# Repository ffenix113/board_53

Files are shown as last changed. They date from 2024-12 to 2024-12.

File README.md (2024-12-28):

# board_53

An Arduino Nano-sized board based on [nRF5340](https://www.nordicsemi.com/Products/nRF5340).
Idea is to have modern and accessible alternative to a sea of nRF52840 boards.

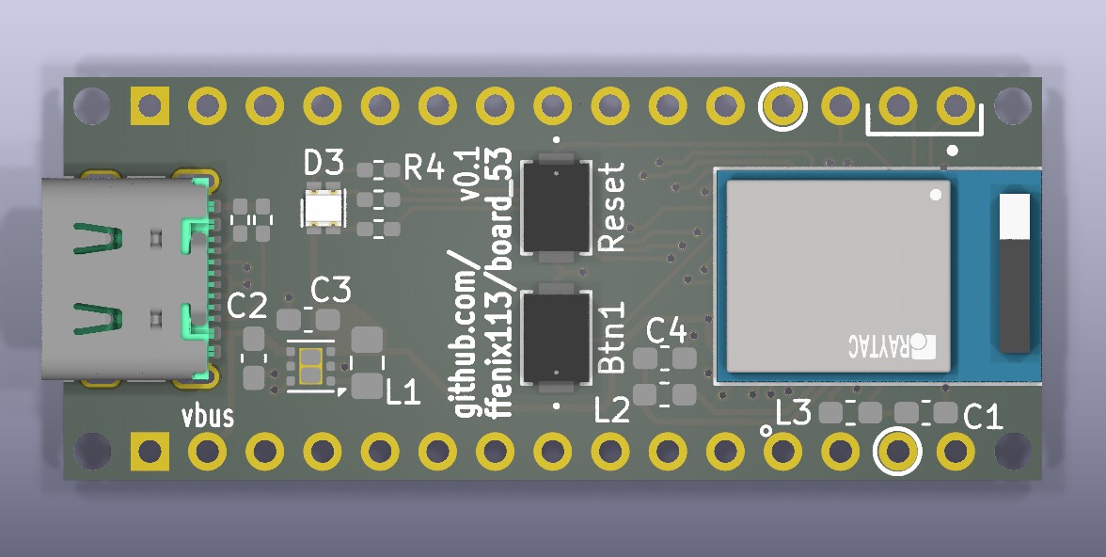
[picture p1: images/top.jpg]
top

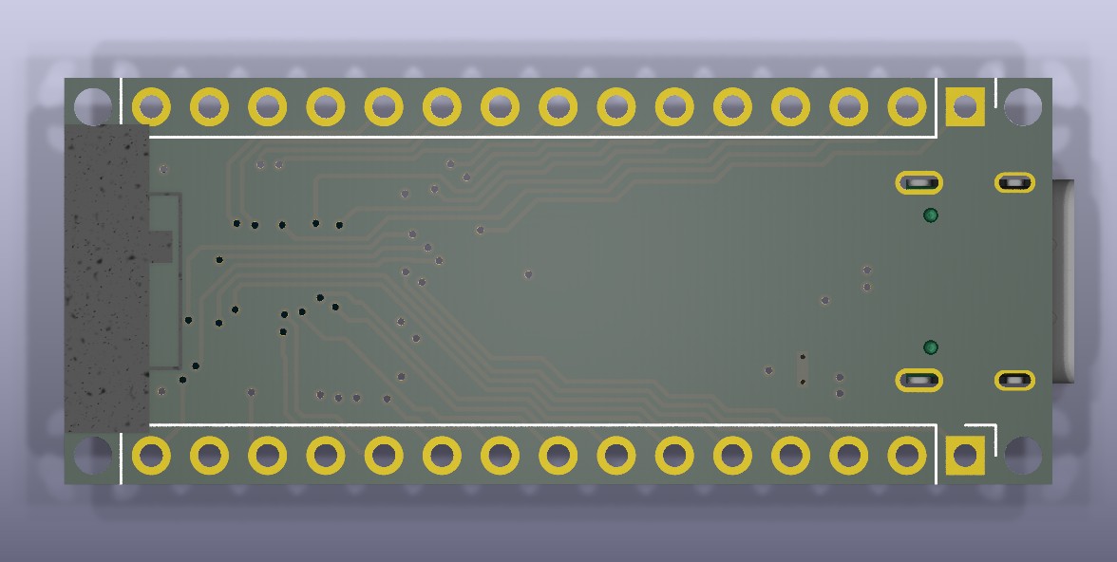
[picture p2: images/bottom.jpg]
bottom


## Features
* Similar, but not identical, pinout to [Arduino Nano 33 BLE](https://docs.arduino.cc/hardware/nano-33-ble/).
* Based on Raytac [MDBT53-1M](https://www.raytac.com/product/ins.php?index_id=121) (nRF5340).
* USB-C connector.
* RGB LED.
* Uses TI [TPS62291](https://www.ti.com/lit/ds/symlink/tps62293.pdf) for better efficiency. This also allows to use batteries in 2.3-6.0 V range (no on-board charger).
* Two buttons: Reset & User configurable.
* SWD pins on the edges.
* Chip antena for better wireless.
* Rather easy to solder this board at home.

## Notes
1. This board is not (yet?) available in Zephyr. Zephyr board definition from this repository should be used when building for this board.
2. Board will be revisioned to improve & simplify design.
3. Buck converter is used to improve efficiency, but maybe will be converted for LDO in next revisions.
4. Bootloader is not required, but MCUBoot can be used as one. UF2 bootloader is not currently (15 Dec, 2024) available for nRF53.
5. There are 0402 resistors in revision 0.1, which will be replaced by 0603(or even 0804) in next revision for easier placing & soldering.

## Contact
* For issues and proposals please use Issues.
* For direct contact please use: board_53@ffenix113.addy.io

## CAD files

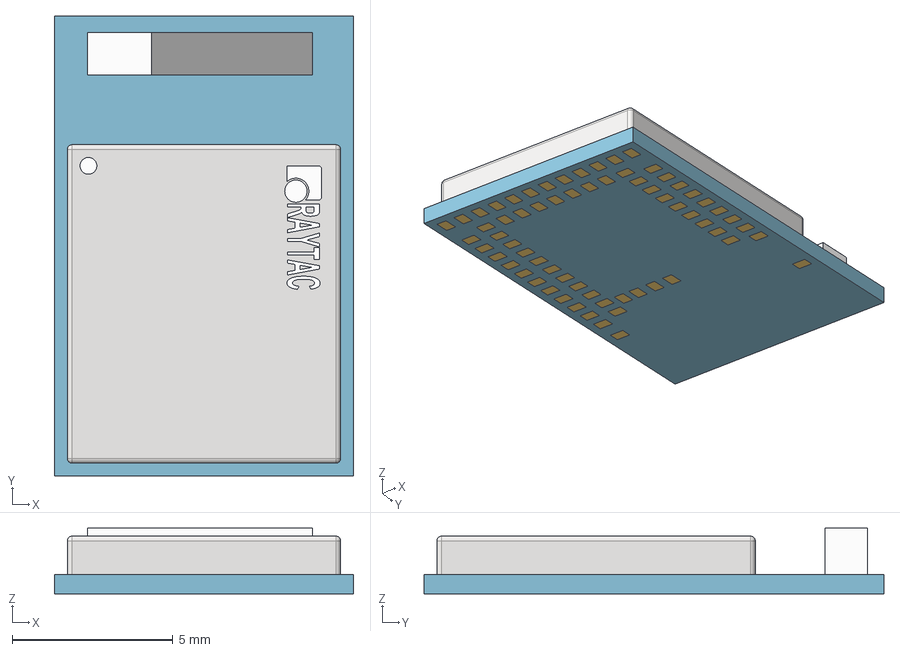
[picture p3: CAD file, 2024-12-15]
models/mdbt53/eec.models/Raytac_-_MDBT53-1M.step
9.30 x 14.3 x 2.05 mm
shield
antenna
logo
marking

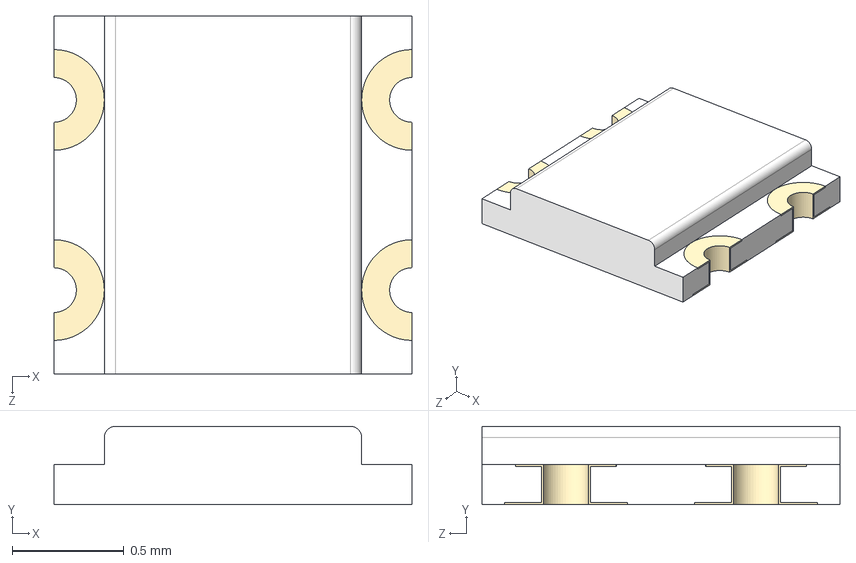
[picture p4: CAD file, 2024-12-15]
models/misc/LTST-C19HE1WT.step
1.60 x 0.35 x 1.60 mm

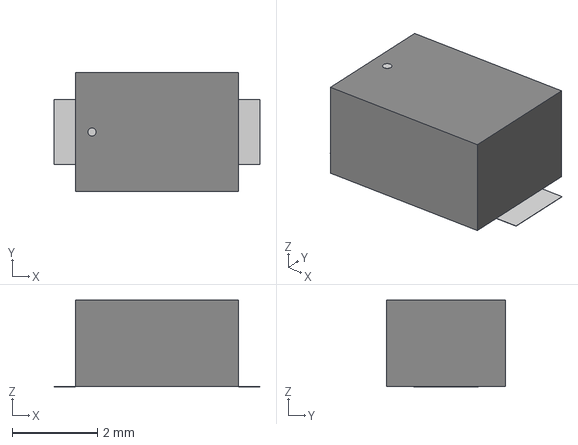
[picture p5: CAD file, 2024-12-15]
models/misc/SW_CS1213AGF260_CRS.step
4.83 x 2.79 x 2.04 mm

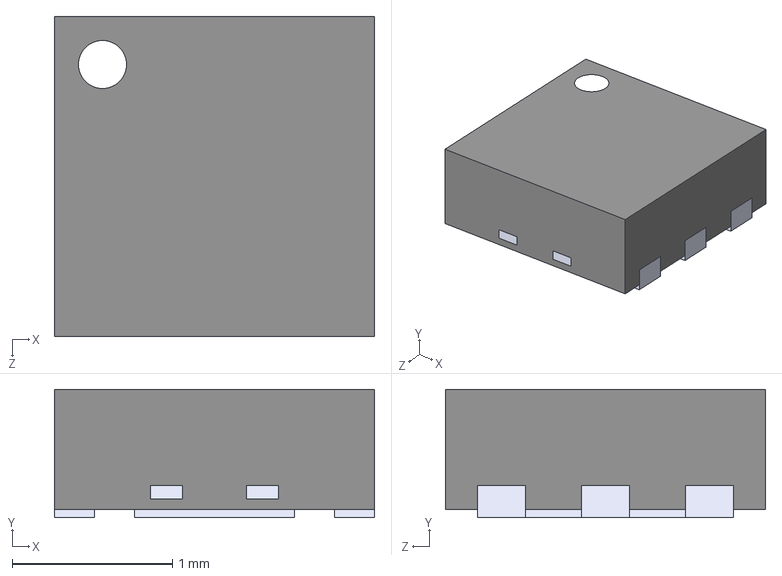
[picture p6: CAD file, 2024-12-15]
models/misc/TPS62291DRVR.step
2.00 x 0.8 x 2.00 mm

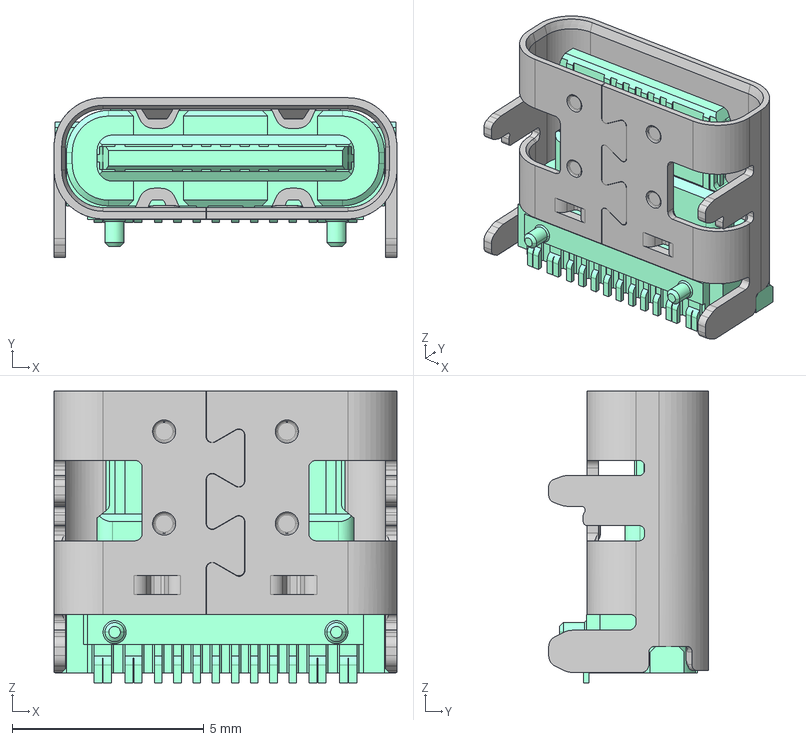
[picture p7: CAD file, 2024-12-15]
models/usb-c/12402012E212A.step
8.94 x 4.16 x 7.60 mm

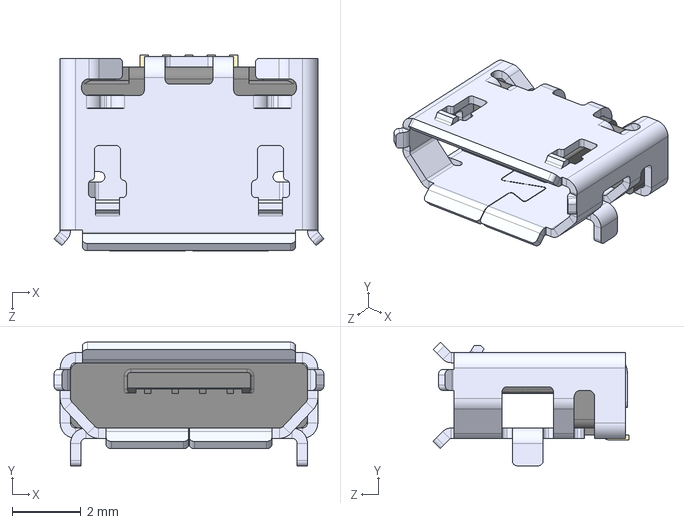
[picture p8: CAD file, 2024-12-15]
models/misc/10118193-0001LF.step
7.86 x 3.60 x 5.71 mm

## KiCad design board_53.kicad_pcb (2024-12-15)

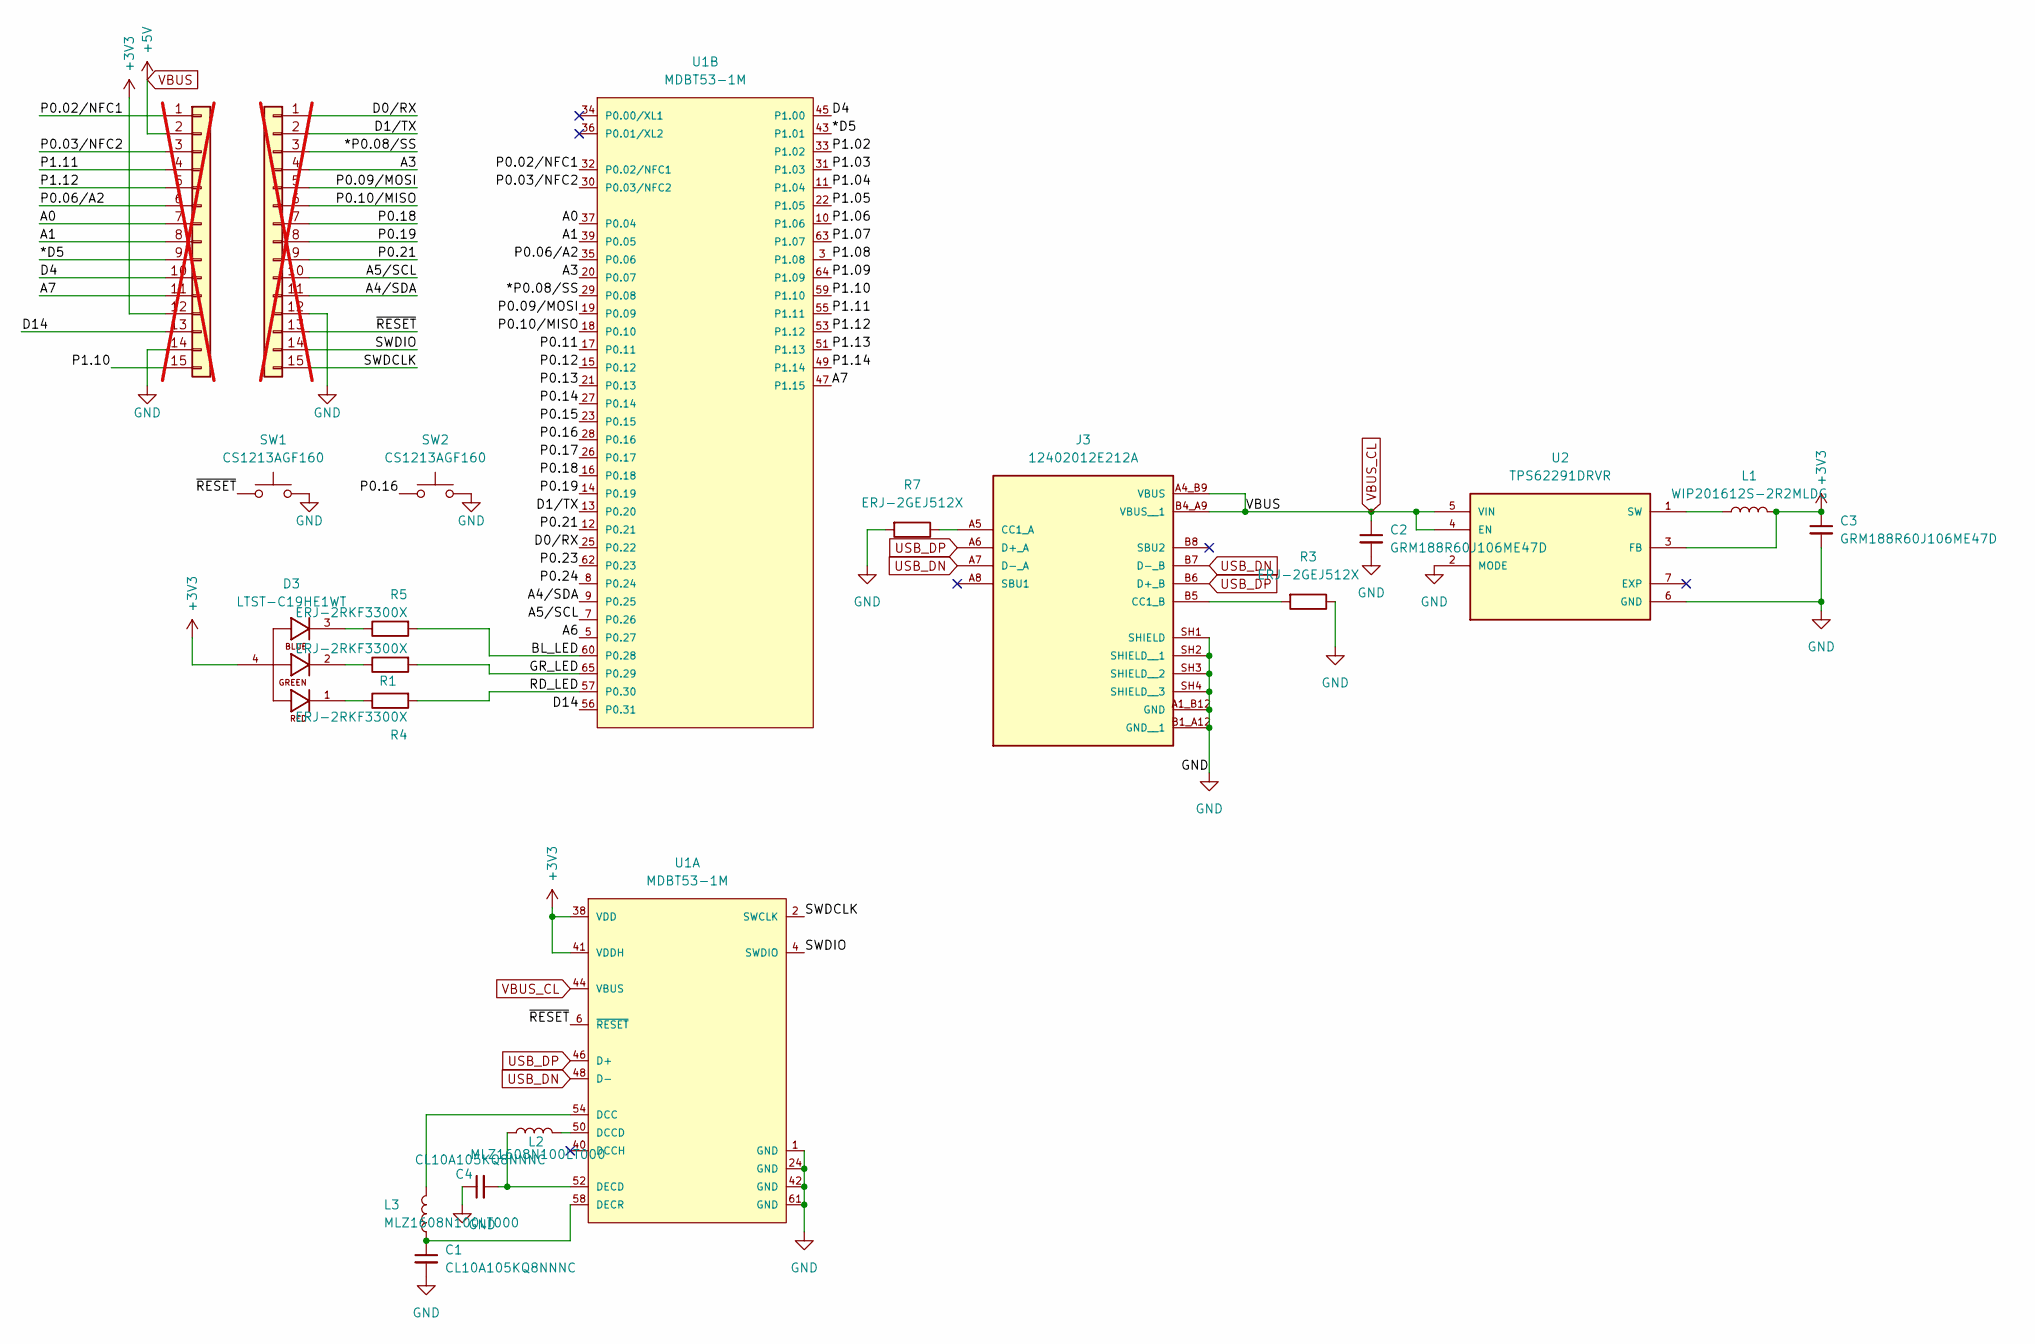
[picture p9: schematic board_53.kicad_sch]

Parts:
C1, C4: CL10A105KQ8NNNC; C_0603_1608Metric_Pad1.08x0.95mm_HandSolder
C2, C3: GRM188R60J106ME47D; C_0603_1608Metric_Pad1.08x0.95mm_HandSolder
D3: LTST-C19HE1WT; LED_LiteOn_LTST-C19HE1WT; PARTREV B
J1: Analog; PinHeader_1x15_P2.54mm_Vertical; not fitted
J2: Digital; PinHeader_1x15_P2.54mm_Vertical; not fitted
J3: 12402012E212A; AMPHENOL_12402012E212A; PARTREV 4
L1: WIP201612S-2R2MLDG; L_0805_2012Metric_Pad1.15x1.40mm_HandSolder
L2, L3: MLZ1608N100LT000; L_0603_1608Metric_Pad1.05x0.95mm_HandSolder
R1, R4, R5: ERJ-2RKF3300X; R_0402_1005Metric_Pad0.72x0.64mm_HandSolder
R3, R7: ERJ-2GEJ512X; R_0402_1005Metric_Pad0.72x0.64mm_HandSolder
SW1, SW2: CS1213AGF160; SW_CS1213AGF260_CRS
U1: MDBT53-1M; Raytac-MDBT53-1M-MFG; digikey description NORDIC NRF5340 CHIP ANTENNA MODU
U2: TPS62291DRVR; WSON-6-1EP_2x2mm_P0.65mm_EP1x1.6mm_ThermalVias; PARTREV G

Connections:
+3V3: C3.1, D3.4, J1.12, L1.2, U1.38 (VDD), U1.41 (VDDH), U2.3 (FB)
/*D5: J1.9, U1.43 (P1.01)
/*P0.08/SS: J2.3, U1.29 (P0.08)
/A0: J1.7, U1.37 (P0.04)
/A1: J1.8, U1.39 (P0.05)
/A3: J2.4, U1.20 (P0.07)
/A4/SDA: J2.11, U1.9 (P0.25)
/A5/SCL: J2.10, U1.7 (P0.26)
/A6: U1.5 (P0.27)
/A7: J1.11, U1.47 (P1.15)
/BL_LED: R5.2, U1.60 (P0.28)
/D0/RX: J2.1, U1.25 (P0.22)
/D1/TX: J2.2, U1.13 (P0.20)
/D4: J1.10, U1.45 (P1.00)
/D14: J1.13, U1.56 (P0.31)
/GR_LED: R1.2, U1.65 (P0.29)
/P0.02/NFC1: J1.1, U1.32 (P0.02/NFC1)
/P0.03/NFC2: J1.3, U1.30 (P0.03/NFC2)
/P0.06/A2: J1.6, U1.35 (P0.06)
/P0.09/MOSI: J2.5, U1.19 (P0.09)
/P0.10/MISO: J2.6, U1.18 (P0.10)
/P0.11: U1.17 (P0.11)
/P0.12: U1.15 (P0.12)
/P0.13: U1.21 (P0.13)
/P0.14: U1.27 (P0.14)
/P0.15: U1.23 (P0.15)
/P0.16: SW2.1, U1.28 (P0.16)
/P0.17: U1.26 (P0.17)
/P0.18: J2.7, U1.16 (P0.18)
/P0.19: J2.8, U1.14 (P0.19)
/P0.21: J2.9, U1.12 (P0.21)
/P0.23: U1.62 (P0.23)
/P0.24: U1.8 (P0.24)
/P1.02: U1.33 (P1.02)
/P1.03: U1.31 (P1.03)
/P1.04: U1.11 (P1.04)
/P1.05: U1.22 (P1.05)
/P1.06: U1.10 (P1.06)
/P1.07: U1.63 (P1.07)
/P1.08: U1.3 (P1.08)
/P1.09: U1.64 (P1.09)
/P1.10: J1.15, U1.59 (P1.10)
/P1.11: J1.4, U1.55 (P1.11)
/P1.12: J1.5, U1.53 (P1.12)
/P1.13: U1.51 (P1.13)
/P1.14: U1.49 (P1.14)
/RD_LED: R4.2, U1.57 (P0.30)
/SWDCLK: J2.15, U1.2 (SWCLK)
/SWDIO: J2.14, U1.4 (SWDIO)
/~RESET: J2.13, SW1.1, U1.6 (~RESET)
GND: C1.2, C2.2, C3.2, C4.1, J1.14, J2.12, J3.A1_B12 (GND), J3.B1_A12 (GND__1), J3.SH1 (SHIELD), J3.SH2 (SHIELD__1), J3.SH3 (SHIELD__2), J3.SH4 (SHIELD__3), R3.1, R7.2, SW1.2, SW2.2, U1.1 (GND), U1.24 (GND), U1.42 (GND), U1.61 (GND), U2.2 (MODE), U2.6 (GND)
unnamed: D3.1, R4.1
unnamed: D3.2, R1.1
unnamed: D3.3, R5.1
unnamed: J3.A5 (CC1_A), R7.1
unnamed: J3.B5 (CC1_B), R3.2
unnamed: L3.2, U1.54 (DCC)
unnamed: L2.2, U1.50 (DCCD)
unnamed: C4.2, L2.1, U1.52 (DECD)
unnamed: C1.1, L3.1, U1.58 (DECR)
unnamed: L1.1, U2.1 (SW)
USB_DN: J3.A7 (D-_A), J3.B7 (D-_B), U1.48 (D-)
USB_DP: J3.A6 (D+_A), J3.B6 (D+_B), U1.46 (D+)
VBUS: C2.1, J1.2, J3.A4_B9 (VBUS), J3.B4_A9 (VBUS__1), U1.44 (VBUS), U2.4 (EN), U2.5 (VIN)

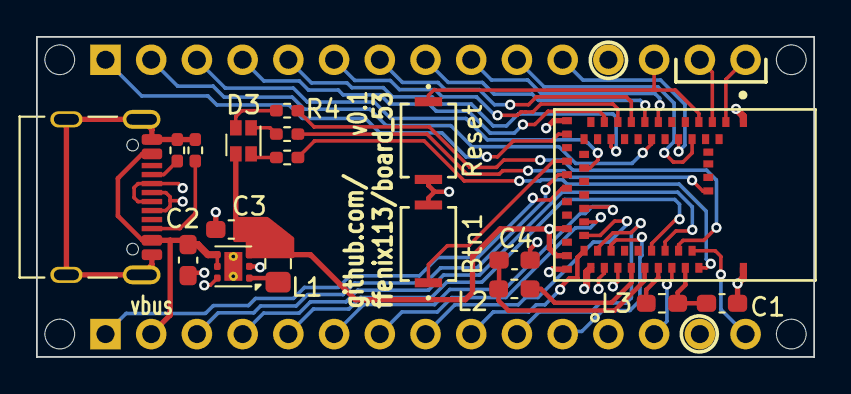
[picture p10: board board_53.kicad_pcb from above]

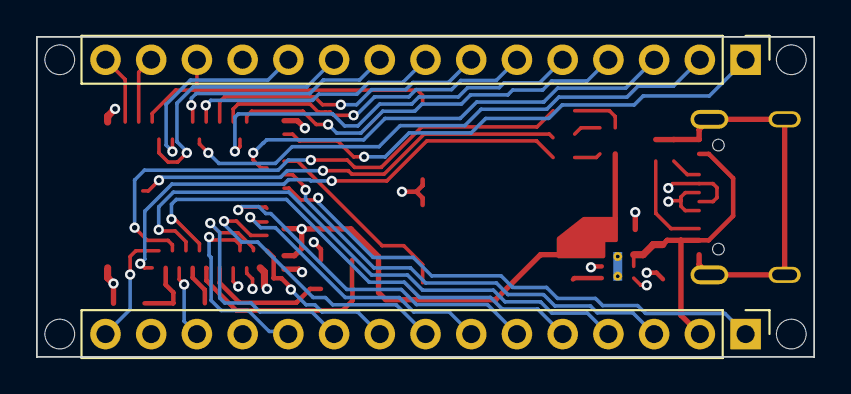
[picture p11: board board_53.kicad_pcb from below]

Board: 4 copper layers, 43.2 x 17.8 mm, 24 parts (2 on the bottom side), 45 nets.

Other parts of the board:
MH1, MH2, MH3, MH4: MountingHole_65mil

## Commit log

2024-10-06 Init files for Board_53
    [board_53.kicad_pcb, board_53.kicad_sch]
2024-12-15 Init commit
    [10118193-0001LF.step, 12402012E212A.step, LTST-C19HE1WT.step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]
2025-09-12 add schematic pdf
